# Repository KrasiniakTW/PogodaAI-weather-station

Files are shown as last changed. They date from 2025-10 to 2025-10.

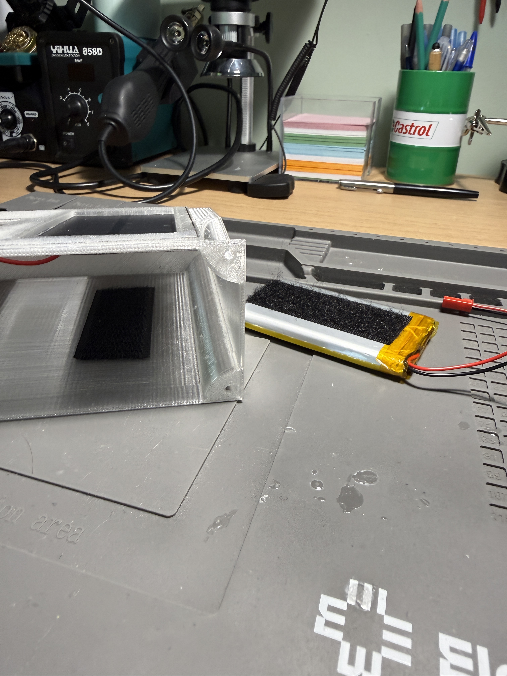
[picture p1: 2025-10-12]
hardware/photos/battery.JPG

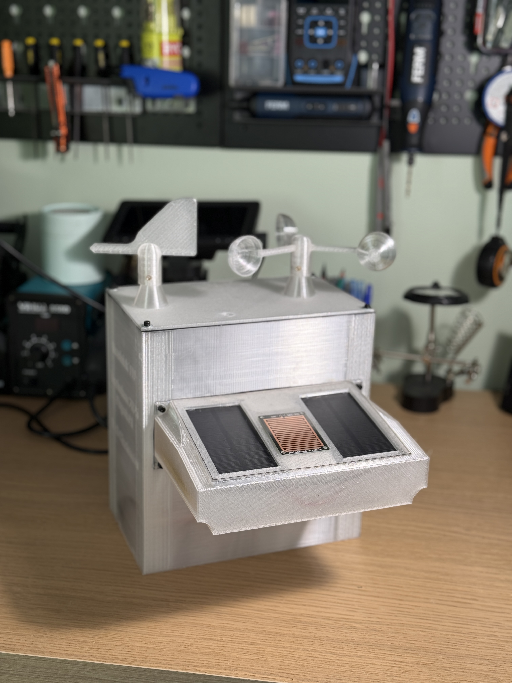
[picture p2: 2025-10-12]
hardware/photos/back.jpg

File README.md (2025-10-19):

# PogodaAI – DIY Solar-Powered Weather & Air Quality Station + AI Forecasting

**Author:** Kamil Gruszczyński  
**Team:** Krasiniak TechWorks  
**Competition:** Technikon ESA 2025  

---

## Project Overview
**PogodaAI** is a fully autonomous, low-cost weather and air quality monitoring station designed for educational, research, and environmental applications.  
It combines **modular hardware** based on the **ESP32 microcontroller** with **solar power management**, a suite of **environmental sensors**, and a **custom AI model** predicting air quality trends.

The entire system is **open-source**, **DIY-friendly**, and designed for easy replication and modification.

!!!Disclaimer!!!
The AI model and training scripts are available in a separate repository:
[PogodaAI-backend](https://github.com/krzkr80/pogodaAI-backend) made by Krzysztof Kurbanow

This repository focuses on the hardware development — including 3D design, electronics, and assembly instructions for the autonomous weather station.

---

## Main Features
- **Energy autonomy:** operates 100% off-grid using a solar panel + Li-Po battery.  
- **Modular architecture:** each sensor and component can be replaced or upgraded independently.  
- **Multi-sensor integration:** PM1.0, PM2.5, PM10 (PMSA003), temperature, humidity, pressure, VOC (BME680), light, rainfall, wind speed, and wind direction.   
- **3D-printed housing:** durable PET-G design, fully documented for easy printing and assembly.  
- **Wireless connectivity:** ESP32 with WiFi transmission and SD card logging.  
- **Open source:** all hardware, firmware, and CAD files are publicly available.

---

## Hardware Overview

| Component | Description |
|---|---|
| **MCU** | ESP32 (WiFi + low power modes) |
| **Air quality** | PMSA003 (PM1.0, PM2.5, PM10) |
| **Environment** | BME680 (Temp, Humidity, Pressure, VOC) |
| **Light** | Analog photodiode |
| **Rain** | YL-83 sensor |
| **Wind** | Custom 3D-printed anemometer + wind vane |
| **Power** | DFRobot Solar Power Manager 5V + Li-Po 3.7 V |
| **Display** | LCD 4×20 + keypad |
| **Storage** | SD card module |
| **Housing** | PET-G 3D printed, modular & weatherproof |

Full electronics schematic available in `hardware/circuit_image.png`  
Assembly and printing instructions included in `/hardware/`.

---

## Custom Mechanical Components

The **anemometer** and **wind vane** were designed specifically for this project:  
- Carbon tubes (10 mm Ø, ~250 mm long)  
- 6200 bearings (2–4 pcs)  
- PET-G 3D printed parts (~100 g)  
- Gap sensor (for rotation counting)  
- Magnet + magnetometer (for direction detection)  

🧭 Detailed explanation: [`PogodaAI_anemometer_and_wind_vane_explained.pdf`](hardware/PogodaAI_anemometer_and_wind_vane_explained.pdf)

---

## Assembly Instructions
Step-by-step build guides are included:
- [`PogodaAI_weather_station_assembly_guide.pdf`](hardware/PogodaAI_weather_station_assembly_guide.pdf)  
- [`PogodaAI_weather_station_electronics_guide.pdf`](hardware/PogodaAI_weather_station_electronics_guide.pdf)  
- [`PogodaAI_printing_guide.pdf`](hardware/PogodaAI_printing_guide.pdf)

---

## Environmental Impact
- Promotes local awareness of air quality
- Enables early warnings for smog and pollution events
- Supports schools and communities with open monitoring tools
- 100% renewable power supply, zero operating cost
- Designed from recyclable PET-G materials

---

## Contributing
We welcome community contributions!
You can:
- Submit improvements to the AI model
- Modify hardware design for local conditions
- Translate documentation into other languages
- Please open a Pull Request or Issue on GitHub.

---

## License
This project is licensed under the MIT License – you are free to use, modify, and distribute it with attribution.

---

## Gallery
PogodaAI Autonomiczna Stacja pogodowa
circuit_image

---

## Contact
Krasiniak TechWorks
- techworks@krasiniak.pl
- GitHub: github.com/KrasiniakTW i github.com/krzkr80

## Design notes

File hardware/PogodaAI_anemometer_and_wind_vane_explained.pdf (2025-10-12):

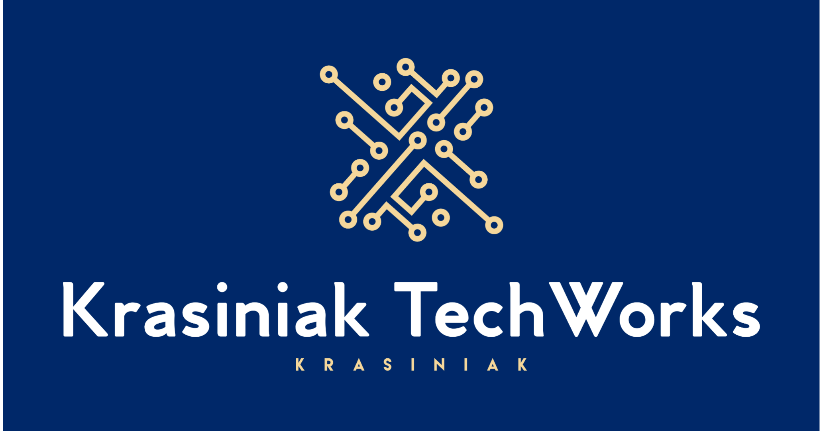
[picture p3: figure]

## PogodaAI anemometer and wind vane explained

Author: Kamil Gruszczyński
Team: Krasiniak TechWorks

Anemometer and wind vane were custom designed for cost saving and for better fitment in this project. The only required elements are:
- two carbon tubes (10mm outer diameter) of length at least 250mm each
- 2-4 6200 bearings (preferably unarmed - no rubber/metal guards)
- ~100g of PETG filament
- one neodymium magnet
- magnetometer of your choice
- gap sensor (with at least 10mm of working area)

How does our anemometer work?
As shown on a diagram below - the gap sensor sends data to MCU every time there is a hole in a plastic disc. If we have 12 holes the controller can calculate how fast it is spinning using basic formulas. In a 5 second measurement period all free light passes are counted giving an average speed in those 5 seconds. It is a very easy and durable mechanism.

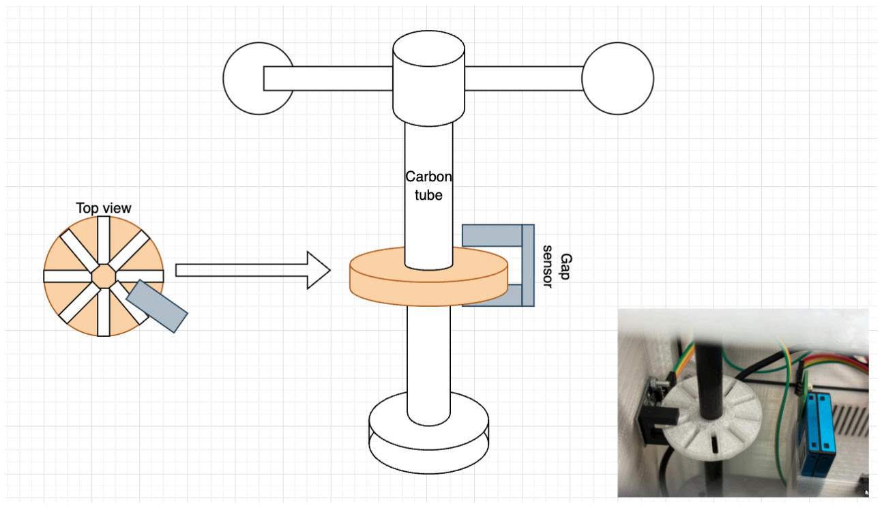
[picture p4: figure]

How does our wind vane work?
The principle behind this mechanism is a bit more complicated. There is a magnet facing the same direction as the arrow on top. When wind rotates the top part, the whole tube moves with this magnet. The magnetometer is placed as close to the rod on the bottom of the main housing. The magnet makes it “think” that the north pole is in the same way as the magnet is facing. Knowing that the weather station is facing south (for the best solar panels efficiency) we can calculate which way the wind is blowing.

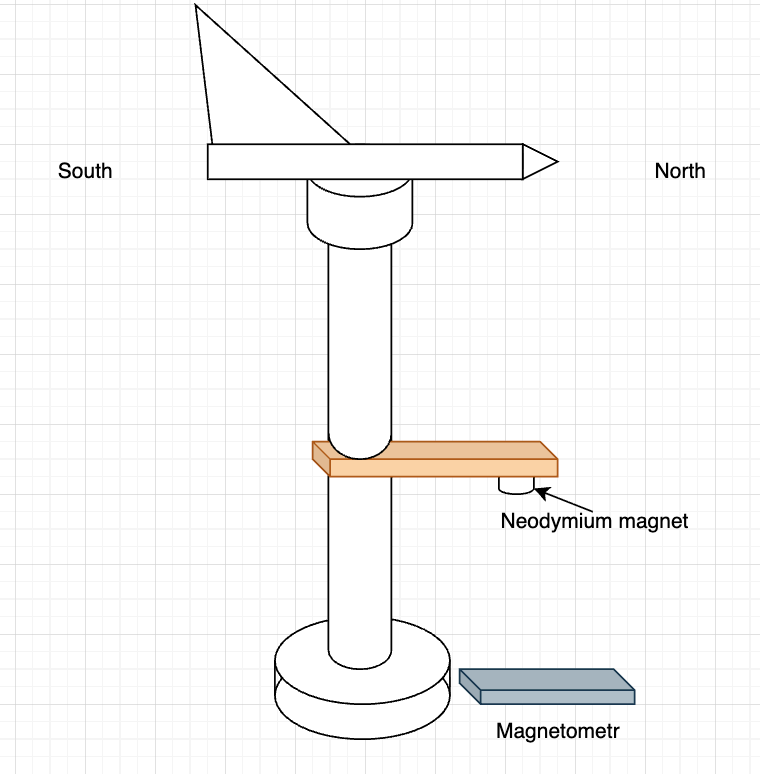
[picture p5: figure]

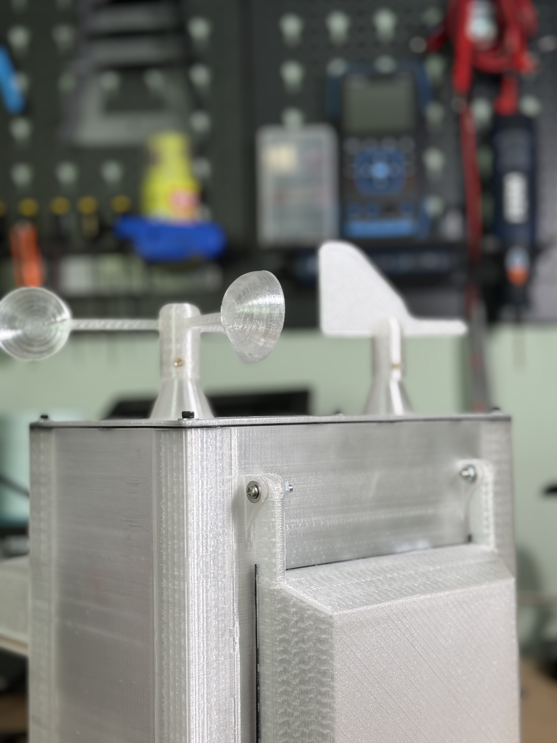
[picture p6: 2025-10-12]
hardware/photos/top.jpg

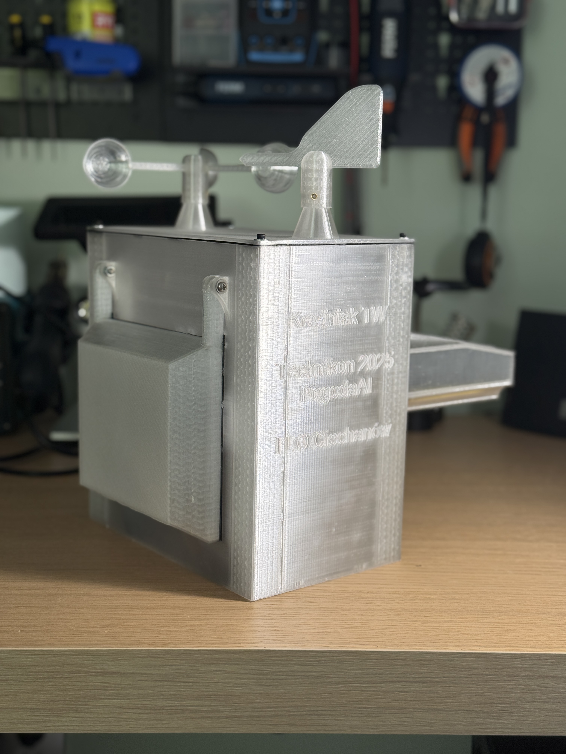
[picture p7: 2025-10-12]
hardware/photos/front.jpg

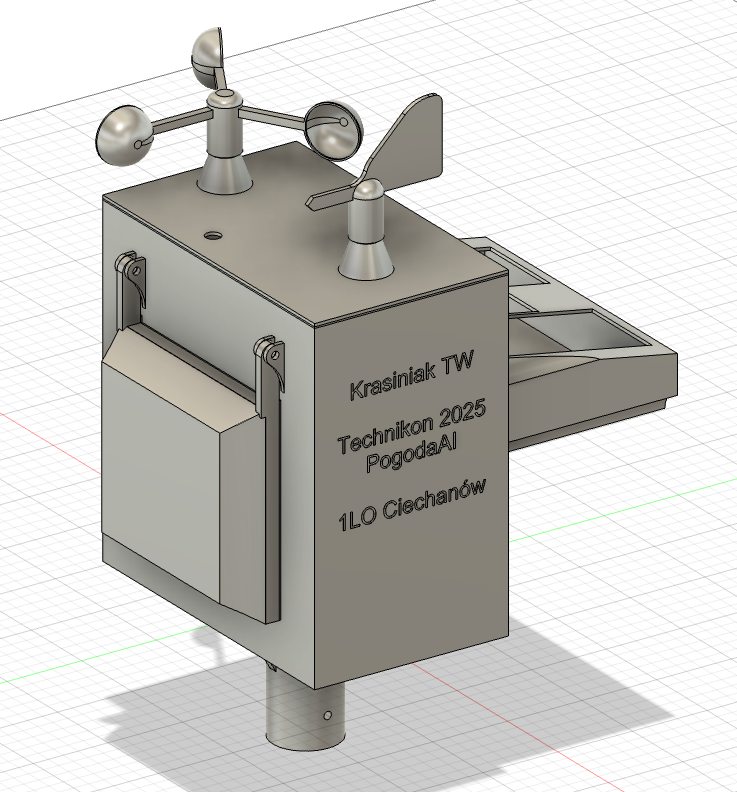
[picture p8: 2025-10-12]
hardware/photos/final_look.png

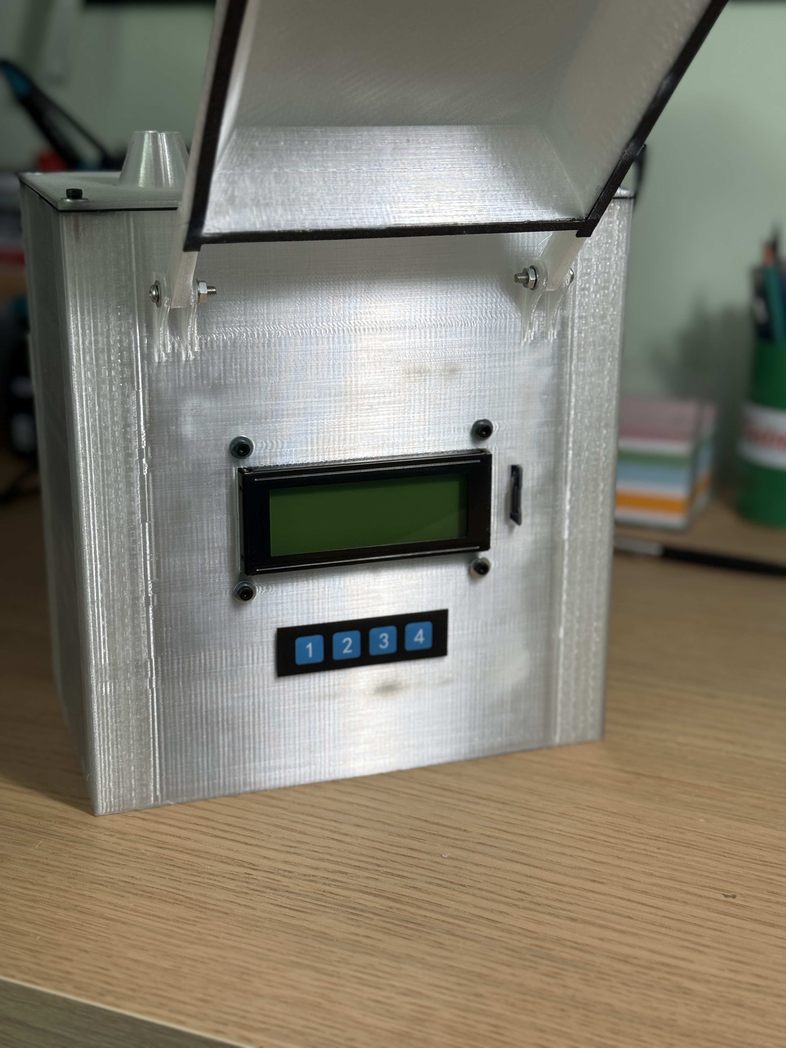
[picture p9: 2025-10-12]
hardware/photos/control_panel.jpg

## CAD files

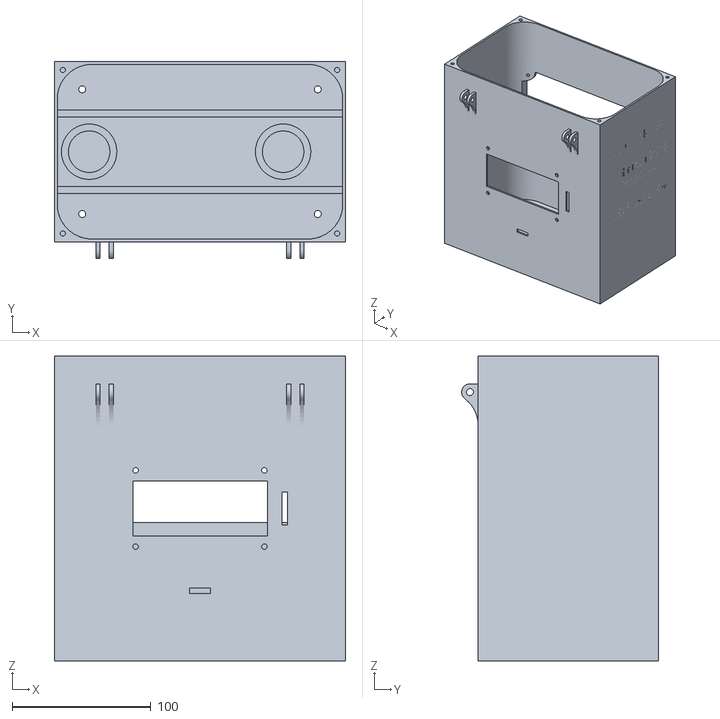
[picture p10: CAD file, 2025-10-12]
hardware/3d_models/stl/main_housing.stl
210.0 x 142.0 x 220.0

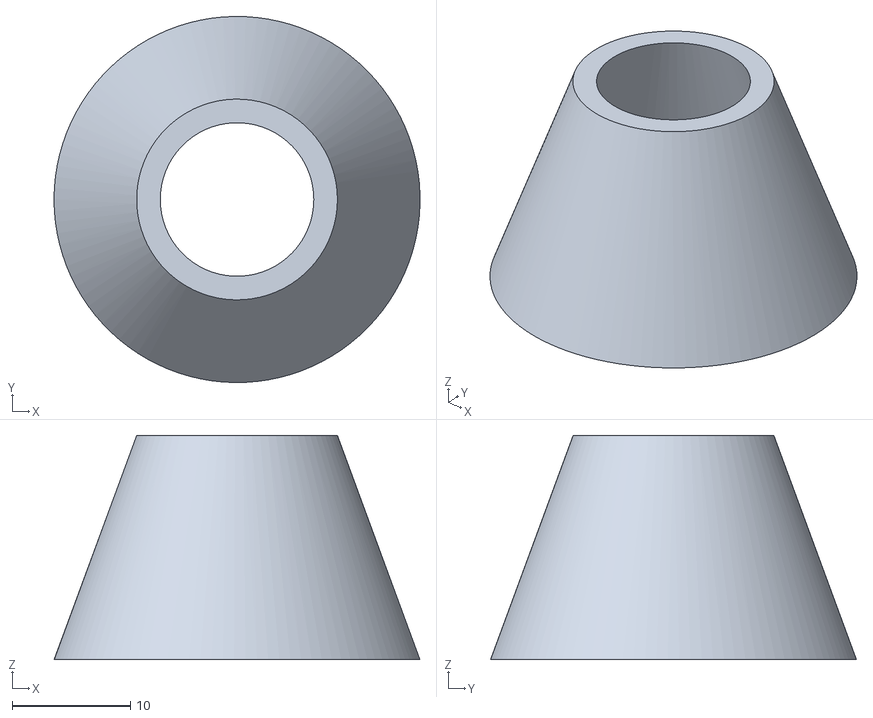
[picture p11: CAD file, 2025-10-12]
hardware/3d_models/stl/cap.stl
31.0 x 31.0 x 19.0

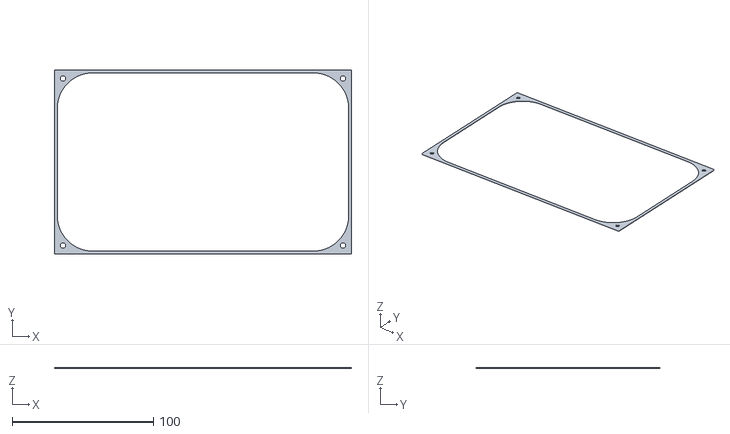
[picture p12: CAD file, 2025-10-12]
hardware/3d_models/stl/seal_1.stl
210.0 x 130.0 x 1.00

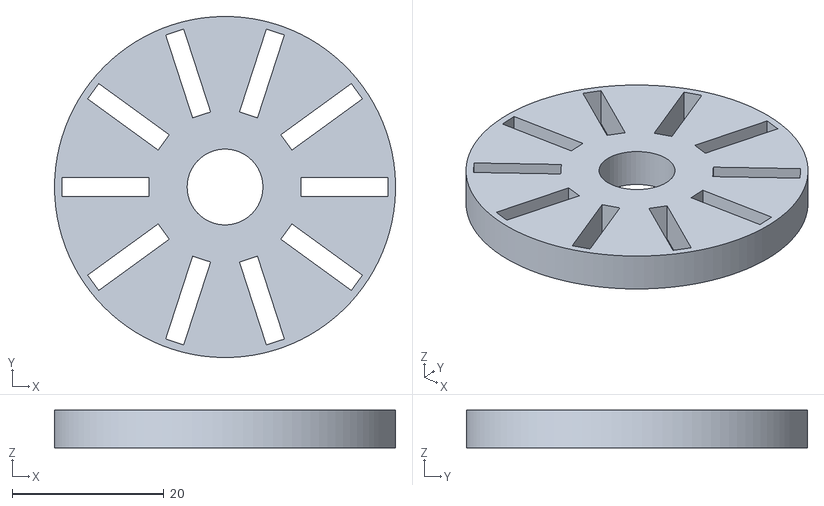
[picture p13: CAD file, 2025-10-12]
hardware/3d_models/stl/anemometer_wheel.stl
45.0 x 45.0 x 5.00

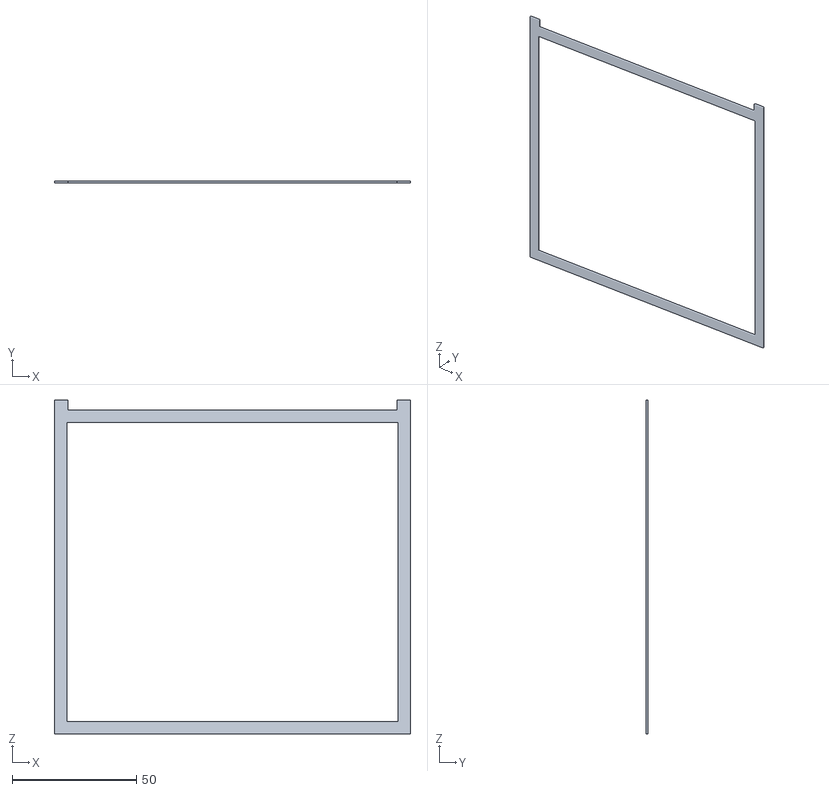
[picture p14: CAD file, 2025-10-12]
hardware/3d_models/stl/seal_3.stl
143.0 x 1.00 x 134.0

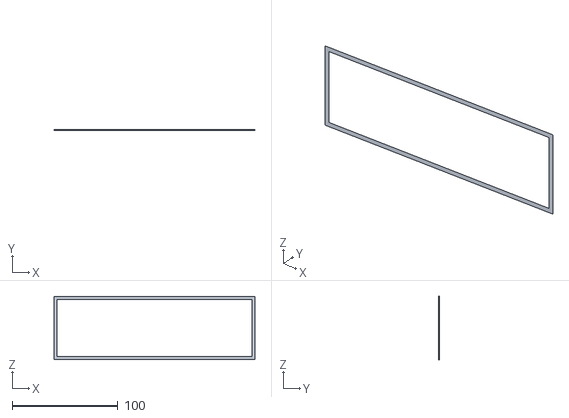
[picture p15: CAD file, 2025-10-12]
hardware/3d_models/stl/seal_2.stl
190.0 x 0.3 x 60.0

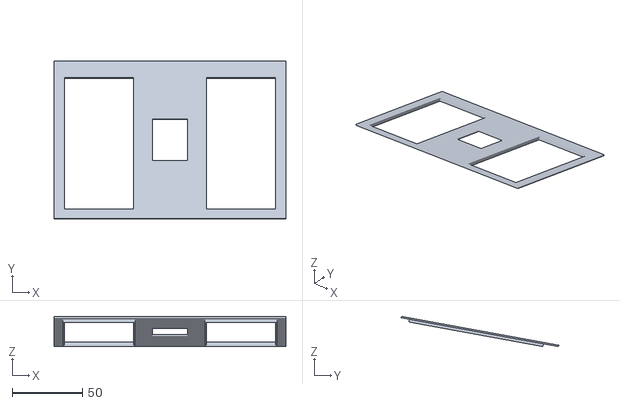
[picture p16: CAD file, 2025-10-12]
hardware/3d_models/stl/solar_panels_cover.stl
165.2 x 112.3 x 21.5

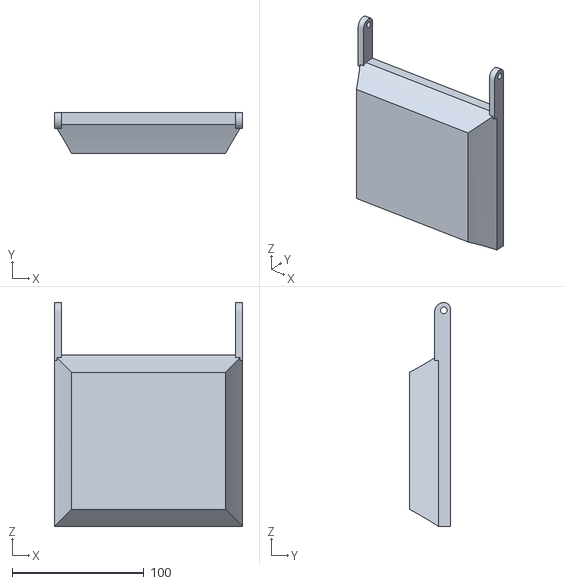
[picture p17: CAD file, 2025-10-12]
hardware/3d_models/stl/front_cover.stl
143.0 x 31.0 x 170.0

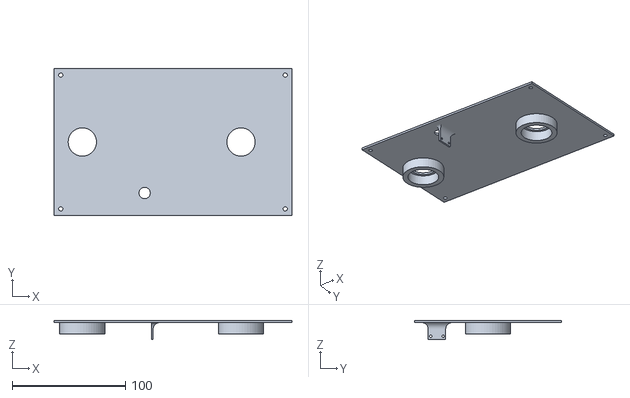
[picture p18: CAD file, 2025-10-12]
hardware/3d_models/stl/top_cover.stl
210.0 x 130.0 x 17.0

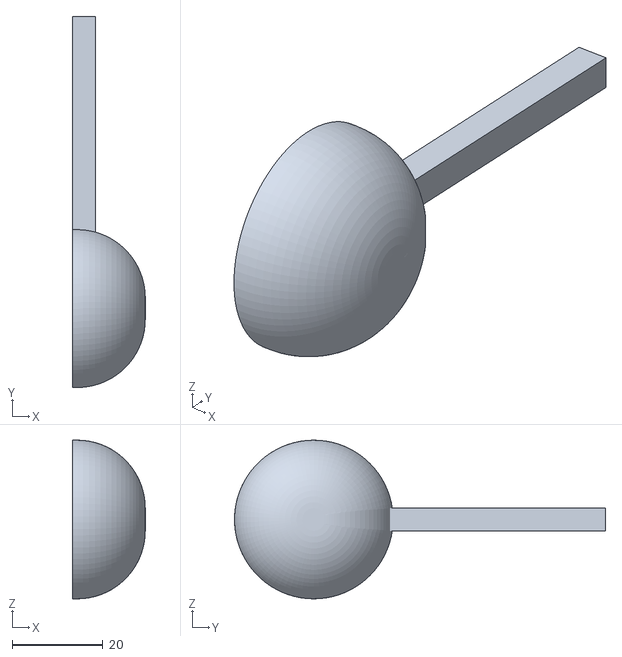
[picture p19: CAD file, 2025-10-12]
hardware/3d_models/stl/anemometer_arm.stl
16.0 x 81.8 x 35.0

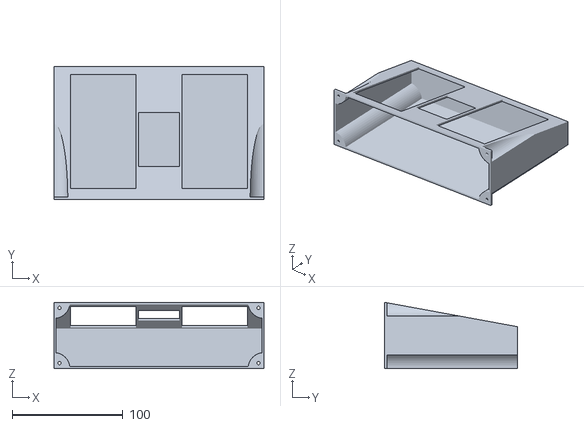
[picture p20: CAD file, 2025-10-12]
hardware/3d_models/stl/solar_panels_housing.stl
190.0 x 120.0 x 60.0

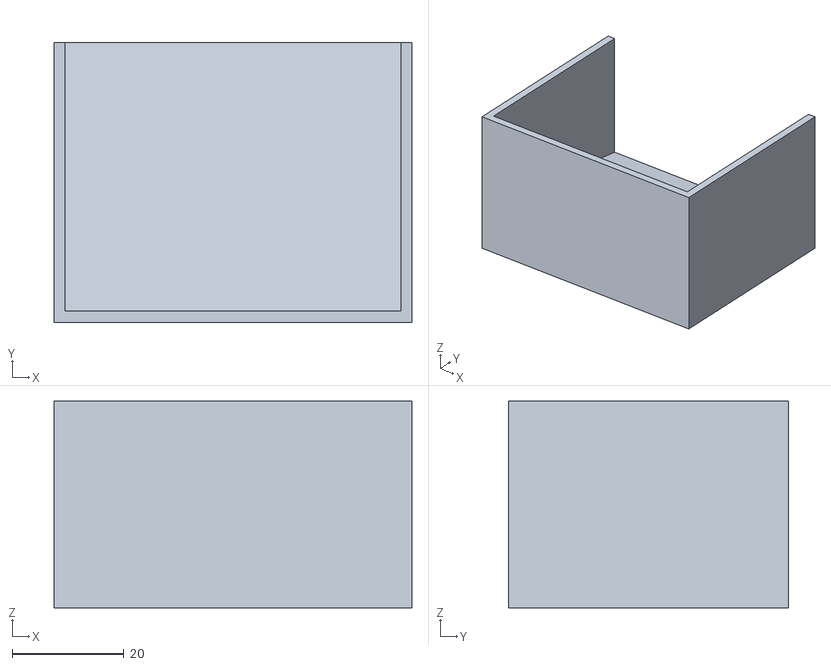
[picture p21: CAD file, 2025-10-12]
hardware/3d_models/stl/PMS_housing.stl
64.0 x 50.0 x 37.0

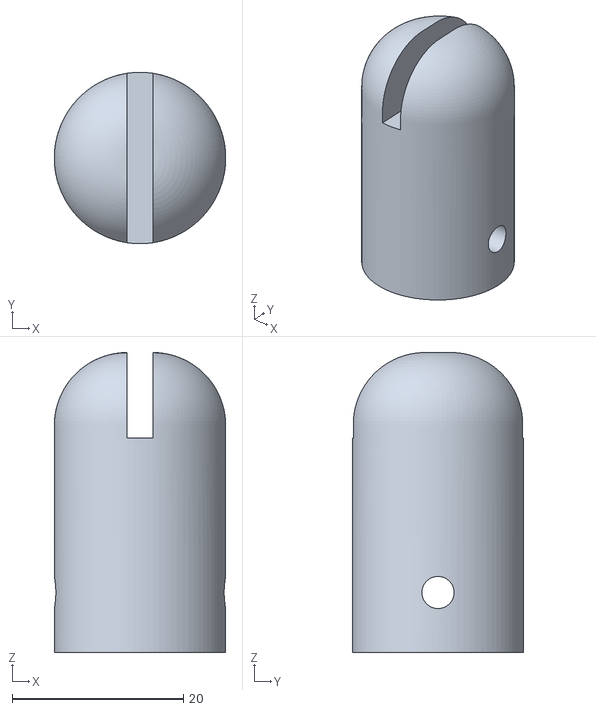
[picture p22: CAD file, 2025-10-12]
hardware/3d_models/stl/wind_vane_base.stl
20.0 x 20.0 x 35.0

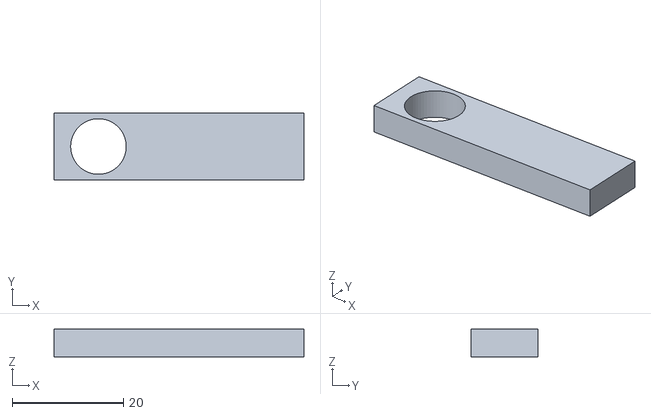
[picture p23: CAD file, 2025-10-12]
hardware/3d_models/stl/wind_vane_magnet_arm.stl
45.0 x 12.0 x 5.00

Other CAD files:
hardware/3d_models/stl/SD_reader_holder.stl
hardware/3d_models/stl/anemometer_base.stl
hardware/3d_models/stl/wind_vane_arrow.stl
hardware/3d_models/f3d/weather_station_v10.f3d

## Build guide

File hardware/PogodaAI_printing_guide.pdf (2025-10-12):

## PogodaAI printing guide

Author: Kamil Gruszczyński
Team: Krasiniak TechWorks

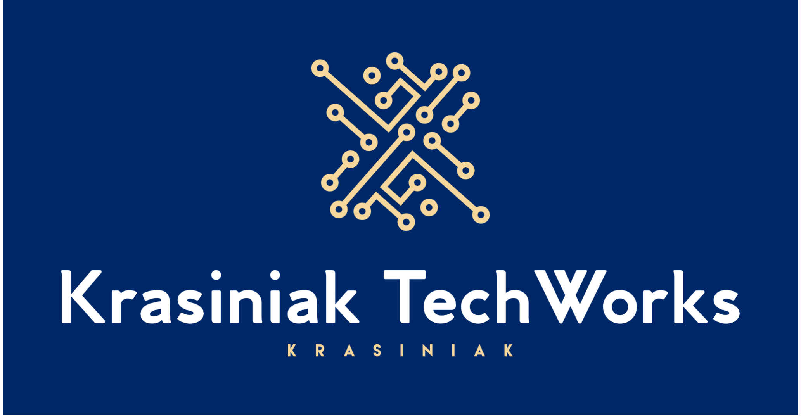
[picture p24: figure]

All of the parts should be printed with PET-G filament, except files named seal_x.stl. PET-G is required because of its resistance to outside environment - waterproofability, high melting point, uv resistancy.

Files with name seal_x.stl have to be printed with TPU-95a.
File cap.stl has to be printed twice.
File anemometer_arn.stl has to be printed 3 times.

Support are required only for:
- solar_panels_housing.stl
- main_housing.stl
- front_cover.stl

All .stl files are ready in the /3d_models folder.

Minimum working size of a 3d printer is 210x210x220 mm.

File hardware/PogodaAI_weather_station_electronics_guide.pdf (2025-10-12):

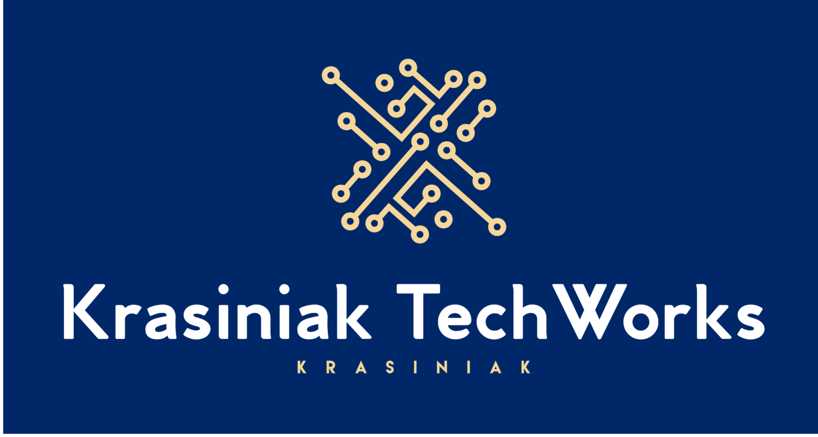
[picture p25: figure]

## PogodaAI weather station electronics guide

Author: Kamil Gruszczyński
Team: Krasiniak TechWorks

Tools and equipment needed for assembly:
- ~1m 24AWG power cables (red and black)
- one set of jumper wires (male-male) or (male-female)

1
- All of the sensors and other components stated in BOM
- Two M3 screws for wood/plastic
- Philips screwdriver
- ~5cm of velcro
- Hot glue
- Soldering iron, short solid wire cables, male headers, double sided universal board -only if you are making DIY PCB

The whole weather station assembly guide is in the same directory. Look for: PogodaAI assembly guide

Electronics diagram can be found under circuit_image.png.

Note: If you want to make a more clear project it is recommended to solder your own DIY PCB. In that case you should solder the ESP32 board directly to the universal board. Remain even spacing from all sides of the board. The project will work the best if you make male headers for jumper cables with spacing of one free hole. Always try to route ground wires away from the PCB antenna on MCU board. We recommend:
- One 6-pin header for SD card reader
- Five 4-pin headers for all I2C devices (Caution! Check for SDA and SCL order. May differ between modules)
- One 4-pin header for UART communication with PMSA003 sensor
- Three 3-pin headers for raindrop/light/wind speed sensors
- One 5-pin header for keypad
You can also add a PCB switch before VCC connection with MCU.

Example PCB

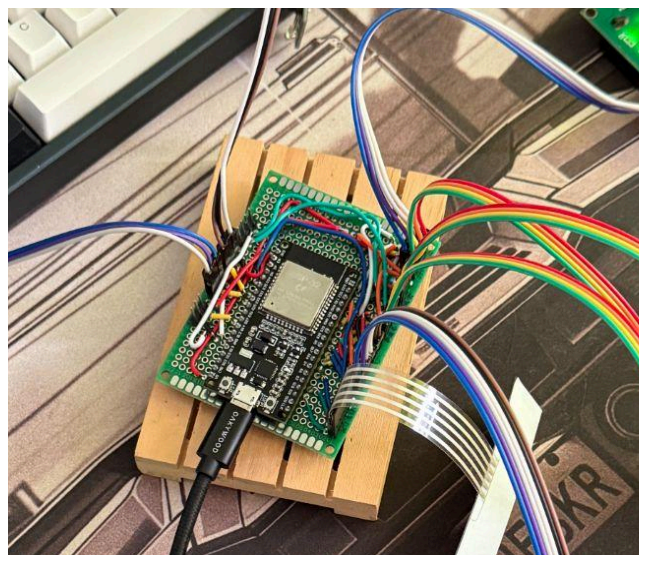
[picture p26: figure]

1 male-male wires in case of making DIY 2 sided PCB, male-female in case of connecting sensors straight to MCU

## Pinout

Pinout that has been used in our code is specified below:

Keypad
2 15 nc 4 gnd

All I2C devices:
SDA - 21
SCL - 22

For PMSA003:
PMS RX - 17
PMS TX - 16

For SD card reader:
CS - 5
Miso - 23
Mosi - 19
SCK - 18

Raindrop sensor:
Signal - 33 (Analog)

Light sensor:
Signal - 32 (Analog)

Anemometer:
Signal - 27 (Digital)

All of them can be changed to your liking. Remember to use accessible pins and only those which are capable of carrying the signal going through them.

The latest release code along with tester can be found in the /code folder.

!!! Always check for reversed VCC and GND pins !!!

### Assembly tips

Most of the assembly is straightforward and doesn’t require professional knowledge and experience. Some tips for the build:
- The LCD display should be mounted with four M3 bolts on the front plate of the main housing. Use 1-2 washers to distance the screen from 3D print (some pins are slightly higher than the PCB itself) Photo 1
- The 4-digit keypad can be mounted on the housing with tape on the back of the keypad. Photo 1
- The SD card reader should be mounted with two M2 bolts on the back of the module. It can be glued in as well.
- PMSA003 should be glued on the side of environmental sensors’ housing with the fan facing outside of the frame. BME680 should be glued on any side of the same housing with the sensor just having any airflow. Photo 2
- For the gap sensor of an anemometer there isn’t any pre-cut hole, because those modules can vary in size. You can glue yours to the side of the housing (making sure it works for rotation) or drill M3 holes for screws with washers. Both solutions are reliable and will work perfectly. Photo 3
- A light sensor is mounted on the top cover. It is recommended to use longer cables for this sensor. Photo 4
- Li-pol batteries can be mounted with velcro in any part of the build. Photo 5
- We recommend screwing in the PCB with at least 2 screws so it doesn’t interfere with moving parts.
Photo 1 | Photo 2

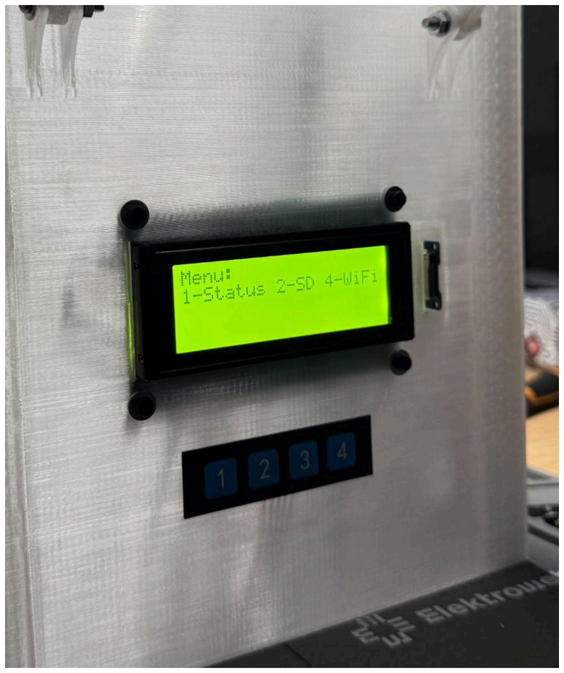
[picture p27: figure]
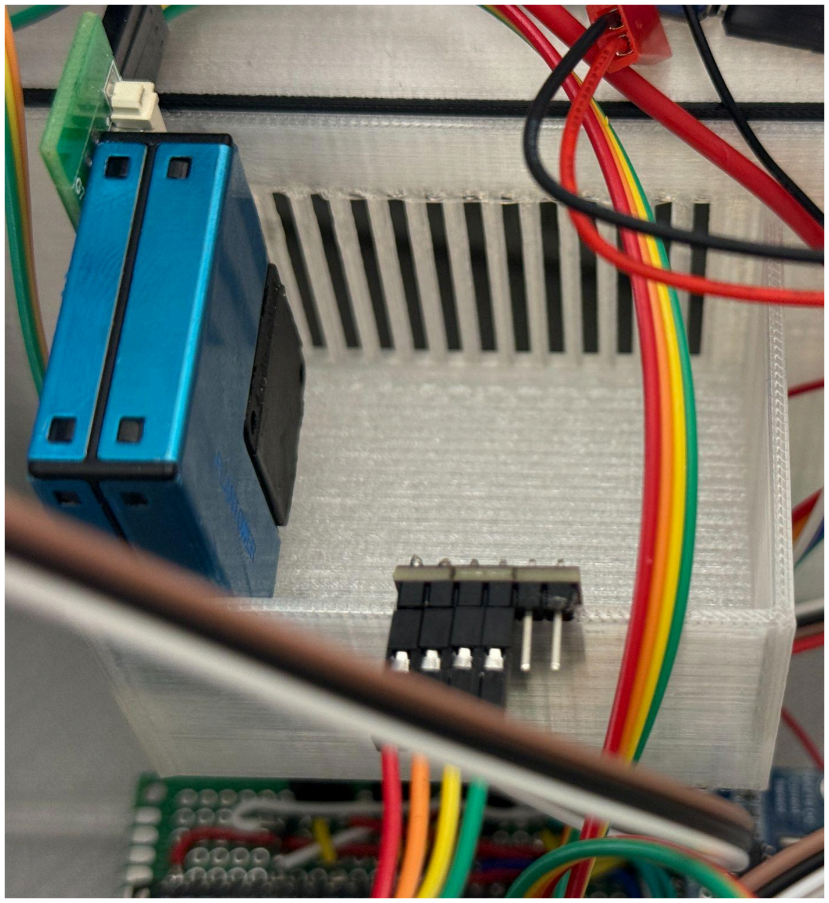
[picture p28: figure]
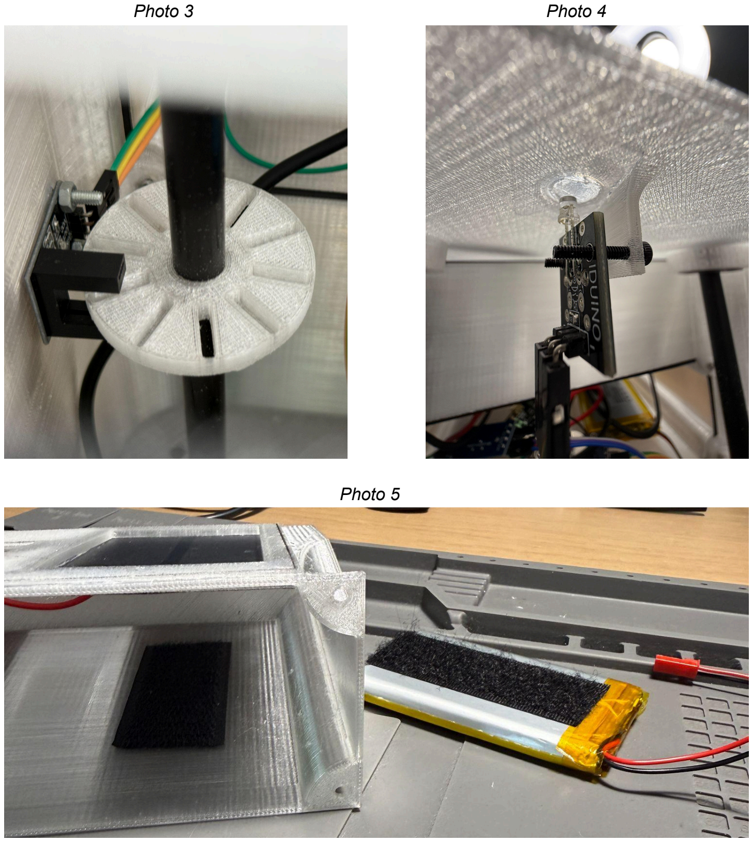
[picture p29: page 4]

Photo 3 | Photo 4

Photo 5

## Circuit diagram

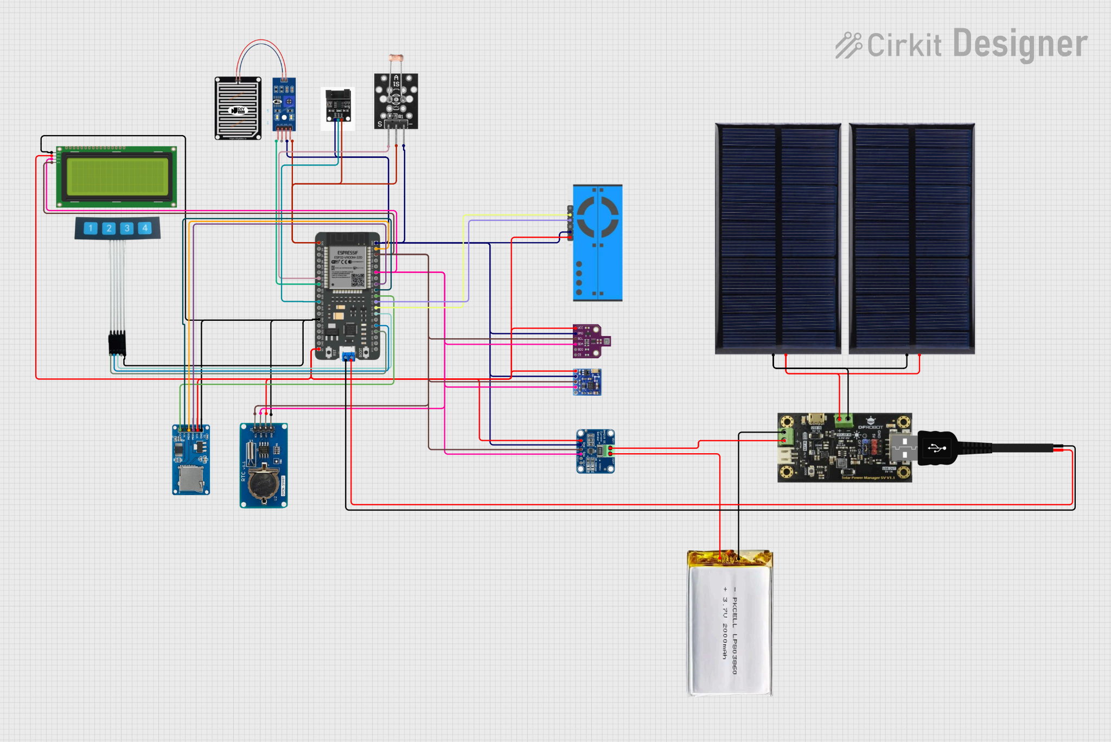
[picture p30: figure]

Made by: Kamil Gruszczyński Designed in: Cirkit Designer

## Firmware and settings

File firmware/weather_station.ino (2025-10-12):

/********************************************************************
  Stacja pogodowa ESP32 - główny kod
  Arduino IDE
  Funkcje:
  - BME680 (Temp, Wilgotność, Ciśnienie, Gas)
  - PMSA003 (PM1, PM2.5, PM10)
  - DS3231 RTC
  - SD logging
  - Anemometr
  - Czujniki deszczu i światła
  - 4x1 klawiatura (pomijamy przycisk 3)
  - I2C LCD 20x4
  - Menu + Wi-Fi hotspot dla pobrania plików
  - Deep sleep z wake on button
********************************************************************/

#include <Wire.h>
#include <RTClib.h>
#include <SD.h>
#include <SPI.h>
#include <LiquidCrystal_I2C.h>
#include "Zanshin_BME680.h"
#include "Adafruit_PM25AQI.h"
#include <Adafruit_Sensor.h>
#include <Adafruit_HMC5883_U.h>
#include <HardwareSerial.h>
#include <WiFi.h>
#include <WebServer.h>
#include <WiFiAP.h>
#include <Adafruit_INA219.h>

/************************** PINY ******************************/
#define KEY1 2
#define KEY2 15
#define KEY4 4

#define RAIN_PIN 33
#define LIGHT_PIN 32
#define ANEMOMETER_PIN 27

#define ANEMOMETER_RADIUS_M 0.08
#define WIND_CALIBRATION 1.0

#define SD_CS 5

#define I2C_SDA 21
#define I2C_SCL 22

#define PMS_RX 17
#define PMS_TX 16

/************************** STAŁE / ZMIENNE ******************************/
const uint32_t SERIAL_SPEED = 115200;
const uint32_t MEASURE_INTERVAL_SEC = 300;  // interwał deep sleep w sekundach
const uint32_t MENU_ACTIVE_SEC = 30;        // ile sekund stacja pozostaje aktywna po wybudzeniu
const uint8_t ANEMOMETER_HOLES = 12;        // liczba otworów w kole anemometru

RTC_DS3231 rtc;
BME680_Class BME680;
LiquidCrystal_I2C lcd(0x27, 20, 4);
Adafruit_INA219 ina219;
Adafruit_HMC5883_Unified mag = Adafruit_HMC5883_Unified(12345);

HardwareSerial pmSerial(2);
Adafruit_PM25AQI aqi;

File logFile;

// zmienne do anemometru
volatile uint16_t anemometerCount = 0;

//zmienne do czujnika deszczu
int lastRainValue = 0;

// Wi-Fi hotspot
const char* AP_SSID = "StacjaPogodowa_ESP32";
const char* AP_PASSWORD = "12345678";
WebServer server(80);

// zmienne do menu
bool menuActive = false;
unsigned long menuStartMillis = 0;

// zmienna do karty SD
bool sdActive = true;

void IRAM_ATTR anemometerISR() {
  anemometerCount++;
}

int batteryPercentage(float voltage) {
  // zakres przybliżony: 4.20V (100%) → 3.20V (0%)
  if (voltage >= 4.20) return 100;
  if (voltage <= 3.20) return 0;
  return (int)((voltage - 3.20) * 100.0 / (4.20 - 3.20));
}

void openLogFile() {
  DateTime now = rtc.now();
  char filename[20];
  sprintf(filename, "/log_%04d%02d%02d.csv", now.year(), now.month(), now.day());
  
  if (SD.exists(filename)) {
    logFile = SD.open(filename, FILE_APPEND);
  } else {
    logFile = SD.open(filename, FILE_WRITE);
    logFile.println("Data,Czas,Temp,Hum,Press,Gas,PM1,PM2_5,PM10,Rain,Light,Wind_RPM,Wind_Speed");
  }

  if (!logFile) {
    Serial.println("Nie mozna otworzyc pliku log!");
    lcd.print("SD open fail!");
  }
}

void readBME680(float &temp, float &hum, float &press, float &gas) {
  int32_t t, h, p, g;
  BME680.getSensorData(t, h, p, g);
  temp = t / 100.0;
  hum  = h / 1000.0;
  press = p / 100.0;
  gas = g / 100.0;
}

bool readPMSA003(uint16_t &pm1, uint16_t &pm25, uint16_t &pm10) {
  PM25_AQI_Data data;
  if (!aqi.read(&data)) return false;
  pm1 = data.pm10_standard;
  pm25 = data.pm25_standard;
  pm10 = data.pm100_standard;
  return true;
}

String headingToDirection(float headingDegrees) {
  String dirs[] = {"N", "NNE", "NE", "ENE", "E", "ESE", "SE", "SSE",
                   "S", "SSW", "SW", "WSW", "W", "WNW", "NW", "NNW"};
  int index = (int)((headingDegrees + 11.25) / 22.5);
  index = index % 16;
  return dirs[index];
}

float readRain() {
  int val = analogRead(RAIN_PIN);
  return (float)val; // opcjonalnie przeliczyć na mm
}

String getRainState(int rainValue, int maxValue = 4095) {
  rainValue = maxValue - rainValue;
  if (rainValue >= maxValue) {
    return "Full";  // zalany czujnik
  } else if (rainValue > lastRainValue) {
    return "Pada";
  } else {
    return "Nie pada";
  }
}

float readLight() {
  int val = analogRead(LIGHT_PIN);
  return (float)val; // opcjonalnie przeliczyć na lux
}

String getLightState(int lightValue, int threshold = 2000) {
  if (lightValue > threshold) {
    return "Dzien";
  } else {
    return "Noc";
  }
}

float calculateWindSpeed(float measurementSeconds, uint16_t &outRevs) {
  noInterrupts();
  uint16_t revs = anemometerCount;
  anemometerCount = 0;
  interrupts();

  outRevs = revs;
  if (measurementSeconds <= 0 || revs == 0) return 0.0;

  float revsPerSec = (float)revs / measurementSeconds;             // impulsy/s
  float rotationsPerSec = revsPerSec / (float)ANEMOMETER_HOLES;    // obr/s
  float circumference = 2.0 * PI * ANEMOMETER_RADIUS_M;            // m
  float windSpeed = rotationsPerSec * circumference * WIND_CALIBRATION; // m/s

  return windSpeed;
}

void logData() {
  if (!logFile) return;

  DateTime now = rtc.now();
  float temp, hum, press, gas, wind;
  uint16_t pm1, pm25, pm10, revs;
  String light, rain;

  readBME680(temp, hum, press, gas);
  readPMSA003(pm1, pm25, pm10);
  rain = getRainState(readRain());
  light = getLightState(readLight());
  lastRainValue = readRain();
  revs = 0;
  wind = calculateWindSpeed((float)MEASURE_INTERVAL_SEC, revs);
  sensors_event_t event; 
  mag.getEvent(&event);
  float heading = atan2(event.magnetic.y, event.magnetic.x);
  float declinationAngle = 0.22; // do korekty później
  heading += declinationAngle;
  if (heading < 0) heading += 2*PI;
  if (heading > 2*PI) heading -= 2*PI;
  float headingDegrees = heading * 180/M_PI;
  String windDir = headingToDirection(headingDegrees);

  char line[200];
  sprintf(line, "%04d-%02d-%02d,%02d:%02d:%02d,%.2f,%.2f,%.2f,%.2f,%d,%d,%d,%s,%s,%lu,%s",
    now.year(), now.month(), now.day(),
    now.hour(), now.minute(), now.second(),
    temp, hum, press, gas,
    pm1, pm25, pm10,
    rain.c_str(), light.c_str(),
    (unsigned long)anemometerCount, windDir.c_str()
  );


  logFile.println(line);
  logFile.flush(); // zapis na SD
}

void checkButtons() {
  if (digitalRead(KEY1) || digitalRead(KEY2) || digitalRead(KEY4)) {
    menuActive = true;
    menuStartMillis = millis();
    lcd.backlight();
    lcd.clear();
    lcd.setCursor(0,0);
    lcd.print("Menu:");
    lcd.setCursor(0,1);
    lcd.print("1-Status 2-SD 4-WiFi");
    delay(300); // debounce
  }
}

void handleMenu() {
  if (!menuActive) return;

  float busvoltage = ina219.getBusVoltage_V();
  float shuntvoltage = ina219.getShuntVoltage_mV() / 1000.0;
  float loadvoltage = busvoltage + shuntvoltage;
  int battPercent = batteryPercentage(loadvoltage);

  if (millis() - menuStartMillis > MENU_ACTIVE_SEC * 1000) {
    menuActive = false;
    lcd.clear();
    lcd.noBacklight();
    return;
  }

  if (digitalRead(KEY1)) { // status
    lcd.clear();
    float temp, hum, press, gas;
    uint16_t pm1, pm25, pm10;
    readBME680(temp, hum, press, gas);
    readPMSA003(pm1, pm25, pm10);
    lcd.setCursor(0,0);
    lcd.printf("T:%.1f H:%.1f", temp, hum);
    lcd.setCursor(0,1);
    lcd.printf("P:%.0f G:%.0f", press, gas);
    lcd.setCursor(0,2);
    lcd.printf("PM2.5:%d PM10:%d", pm25, pm10);
    lcd.setCursor(0,3);
    lcd.printf("Bat:%d", battPercent);
    delay(1000);
  }
  else if (digitalRead(KEY2)) { // safe SD remove / reinit
    lcd.clear();
    if (sdActive) {
      // Odmontowanie karty
      lcd.print("SD off");
      if (logFile) logFile.close();
      SD.end();
      sdActive = false;
    } else {
      // Ponowne zamontowanie karty
      lcd.print("SD init...");
      if (SD.begin(SD_CS)) {
        openLogFile();
        sdActive = true;
        lcd.setCursor(0,1);
        lcd.print("SD ready");
      } else {
        lcd.setCursor(0,1);
        lcd.print("SD fail");
      }
    }
    menuStartMillis = millis();   // reset timera menu
    delay(2000);
  }
  else if (digitalRead(KEY4)) { // Wi-Fi hotspot
    lcd.clear();
    lcd.print("WiFi AP:");
    lcd.setCursor(0,1);
    lcd.print(AP_SSID);
    lcd.setCursor(0,2);
    lcd.print("IP:");
    lcd.print(WiFi.softAPIP());
    delay(2000);
  }
}

void handleFileDownload() {
  DateTime now = rtc.now();
  char filename[20];
  sprintf(filename, "/log_%04d%02d%02d.csv", now.year(), now.month(), now.day());

  if (!SD.exists(filename)) {
    server.send(200, "text/plain", "Brak pliku log");
    return;
  }

  File file = SD.open(filename, FILE_READ);
  if (!file) {
    server.send(200, "text/plain", "Blad otwarcia pliku");
    return;
  }

  server.streamFile(file, "text/csv");
  file.close();
}

void setup() {
  Serial.begin(SERIAL_SPEED);
  delay(100);

  /********** Piny klawiatury **********/
  pinMode(KEY1, INPUT_PULLDOWN);
  pinMode(KEY2, INPUT_PULLDOWN);
  pinMode(KEY4, INPUT_PULLDOWN);

  /********** I2C **********/
  Wire.begin(I2C_SDA, I2C_SCL);

  /********** LCD **********/
  lcd.init();
  lcd.backlight();
  lcd.clear();
  lcd.setCursor(0,0);
  lcd.print("Stacja pogodowa");
  delay(1000);
  lcd.clear();

  /********** RTC **********/
  if (!rtc.begin()) {
    lcd.print("Nie wykryto DS3231!");
    Serial.println("Nie wykryto DS3231!");
    while(1) delay(10);
  }
  if (rtc.lostPower()) {
    rtc.adjust(DateTime(F(__DATE__), F(__TIME__)));
  }

  /********** BME680 **********/
  while (!BME680.begin(I2C_STANDARD_MODE)) {
    Serial.println("BME680 nie znaleziony, retry za 5s...");
    delay(5000);
  }
  BME680.setOversampling(TemperatureSensor, Oversample16);
  BME680.setOversampling(HumiditySensor, Oversample16);
  BME680.setOversampling(PressureSensor, Oversample16);
  BME680.setIIRFilter(IIR4);
  BME680.setGas(320, 150);

  /********** PMSA003 **********/
  pmSerial.begin(9600, SERIAL_8N1, PMS_RX, PMS_TX);
  delay(3000);
  if (!aqi.begin_UART(&pmSerial)) {
    Serial.println("PMSA003 nie znaleziony!");
    lcd.print("PMSA003 blad!");
    while(1) delay(10);
  }

  /********** INA219 **********/
  if (! ina219.begin()) {
    Serial.println("Failed to find INA219 chip");
    while (1) { delay(10); }
  }

  /********** HMC5883 **********/
  if(!mag.begin())
  {
    /* There was a problem detecting the HMC5883 ... check your connections */
    Serial.println("Ooops, no HMC5883 detected ... Check your wiring!");
    while(1);
  }

  /********** SD **********/
  if (!SD.begin(SD_CS)) {
    Serial.println("SD init fail!");
    lcd.print("SD init fail!");
    while(1) delay(10);
  }
  openLogFile(); // otwiera plik dzienny

  /********** Anemometr **********/
  pinMode(ANEMOMETER_PIN, INPUT);
  attachInterrupt(digitalPinToInterrupt(ANEMOMETER_PIN), anemometerISR, RISING);

  /********** Wi-Fi hotspot **********/
  WiFi.softAP(AP_SSID, AP_PASSWORD);
  server.on("/", HTTP_GET, handleFileDownload);
  server.begin();

  /********** Powitalny komunikat **********/
  lcd.clear();
  lcd.setCursor(0,0);
  lcd.print("Stacja gotowa!");
  delay(1000);
  lcd.clear();
}

void loop() {
  checkButtons();   // wybudzenie / menu
  handleMenu();     // obsługa menu

  // Jeśli nie w menu, wykonujemy pomiar i logowanie
  if (!menuActive) {
    logData();
    // przygotowanie do deep sleep
    lcd.clear();
    lcd.noBacklight();
    logFile.close(); // zamknięcie pliku przed deep sleep
    esp_sleep_enable_timer_wakeup(MEASURE_INTERVAL_SEC * 1000000ULL);

    // wake on button
    esp_sleep_enable_ext1_wakeup(
      (1ULL << KEY1) | (1ULL << KEY2) | (1ULL << KEY4),
      ESP_EXT1_WAKEUP_ANY_HIGH
    );

    Serial.println("Wchodzę w deep sleep...");
    delay(100);
    esp_deep_sleep_start();
  }

  server.handleClient(); // obsługa HTTP servera dla hotspot
}

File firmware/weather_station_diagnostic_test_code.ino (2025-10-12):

/********************************************************************
  PogodaAI - Diagnostic Test Code
  Author: Kamil Gruszczyński
  Team: Krasiniak TechWorks
  Purpose:
  - Check if all modules respond correctly
  - Print "OK" or "ERROR" for each component
********************************************************************/

#include <Wire.h>
#include <RTClib.h>
#include <SD.h>
#include <SPI.h>
#include <LiquidCrystal_I2C.h>
#include "Zanshin_BME680.h"
#include "Adafruit_PM25AQI.h"
#include <Adafruit_Sensor.h>
#include <Adafruit_HMC5883_U.h>
#include <HardwareSerial.h>
#include <Adafruit_INA219.h>

#define RAIN_PIN 33
#define LIGHT_PIN 32
#define ANEMOMETER_PIN 27
#define SD_CS 5
#define PMS_RX 17
#define PMS_TX 16
#define I2C_SDA 21
#define I2C_SCL 22

RTC_DS3231 rtc;
BME680_Class bme;
Adafruit_PM25AQI aqi;
Adafruit_INA219 ina219;
Adafruit_HMC5883_Unified mag = Adafruit_HMC5883_Unified(12345);
HardwareSerial pmSerial(2);
LiquidCrystal_I2C lcd(0x27, 20, 4);

volatile uint16_t anemometerCount = 0;
void IRAM_ATTR anemometerISR() { anemometerCount++; }

void setup() {
  Serial.begin(115200);
  delay(500);
  Serial.println("\n=== PogodaAI Diagnostic Test ===");

  // --- I2C init ---
  Wire.begin(I2C_SDA, I2C_SCL);
  Serial.println("I2C initialized.");

  // --- LCD ---
  lcd.init();
  lcd.backlight();
  lcd.print("Diagnostic...");
  Serial.print("LCD: ");
  lcd.setCursor(0, 1);
  lcd.print("LCD OK");
  Serial.println("OK");

  // --- RTC ---
  Serial.print("RTC DS3231: ");
  if (rtc.begin()) {
    Serial.println("OK");
    if (rtc.lostPower()) rtc.adjust(DateTime(F(__DATE__), F(__TIME__)));
  } else Serial.println("ERROR");

  // --- BME680 ---
  Serial.print("BME680: ");
  if (bme.begin(I2C_STANDARD_MODE)) {
    Serial.println("OK");
    int32_t t, h, p, g;
    bme.getSensorData(t, h, p, g);
    Serial.printf("  T: %.2f*C, H: %.2f%%, P: %.2fhPa, G: %.2fKOhm\n",
                  t / 100.0, h / 1000.0, p / 100.0, g / 100.0);
  } else Serial.println("ERROR");

  // --- PMSA003 ---
  Serial.print("PMSA003: ");
  pmSerial.begin(9600, SERIAL_8N1, PMS_RX, PMS_TX);
  delay(2000);
  if (aqi.begin_UART(&pmSerial)) {
    Serial.println("OK");
    PM25_AQI_Data data;
    if (aqi.read(&data))
      Serial.printf("  PM1:%d  PM2.5:%d  PM10:%d\n", data.pm10_standard, data.pm25_standard, data.pm100_standard);
    else Serial.println("  (No data yet)");
  } else Serial.println("ERROR");

  // --- INA219 ---
  Serial.print("INA219 (power): ");
  if (ina219.begin()) {
    Serial.println("OK");
    float busV = ina219.getBusVoltage_V();
    Serial.printf("  Voltage: %.2f V\n", busV);
  } else Serial.println("ERROR");

  // --- Magnetometer ---
  Serial.print("HMC5883L (magnetometer): ");
  if (mag.begin()) {
    Serial.println("OK");
    sensors_event_t event;
    mag.getEvent(&event);
    Serial.printf("  X: %.2f  Y: %.2f  Z: %.2f\n", event.magnetic.x, event.magnetic.y, event.magnetic.z);
  } else Serial.println("ERROR");

  // --- SD Card ---
  Serial.print("SD Card: ");
  if (SD.begin(SD_CS)) {
    Serial.println("OK");
    File f = SD.open("/test.txt", FILE_WRITE);
    if (f) {
      f.println("PogodaAI test log");
      f.close();
      Serial.println("  Write test: OK");
    } else Serial.println("  Write test: ERROR");
  } else Serial.println("ERROR");

  // --- Rain Sensor ---
  Serial.print("Rain Sensor: ");
  int rain = analogRead(RAIN_PIN);
  Serial.printf("OK  (Value: %d)\n", rain);

  // --- Light Sensor ---
  Serial.print("Light Sensor: ");
  int light = analogRead(LIGHT_PIN);
  Serial.printf("OK  (Value: %d)\n", light);

  // --- Anemometer ---
  Serial.print("Anemometer: ");
  pinMode(ANEMOMETER_PIN, INPUT);
  attachInterrupt(digitalPinToInterrupt(ANEMOMETER_PIN), anemometerISR, RISING);
  Serial.println("OK (waiting for pulses...)");

  Serial.println("\n=== Initialization complete ===");
  Serial.println("Rotate anemometer or blow on sensor to test pulses.");
}

void loop() {
  static unsigned long lastPrint = 0;
  if (millis() - lastPrint > 2000) {
    lastPrint = millis();
    Serial.printf("[Test] Rain=%d  Light=%d  Pulses=%u\n",
                  analogRead(RAIN_PIN),
                  analogRead(LIGHT_PIN),
                  anemometerCount);
  }
}
